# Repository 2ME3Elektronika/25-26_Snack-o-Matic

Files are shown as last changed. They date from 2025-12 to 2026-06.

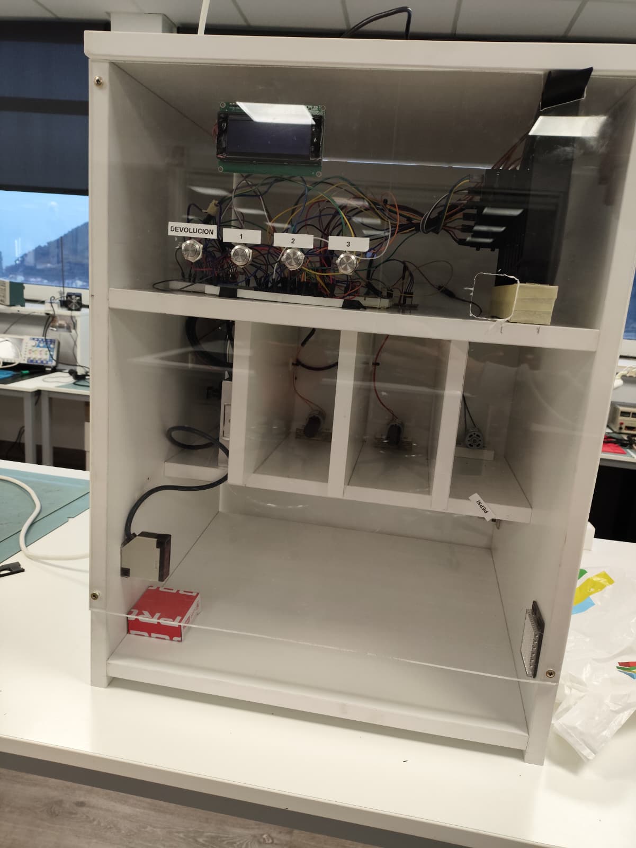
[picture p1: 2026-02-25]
Prototipos/Prototipo foto 2.jpeg

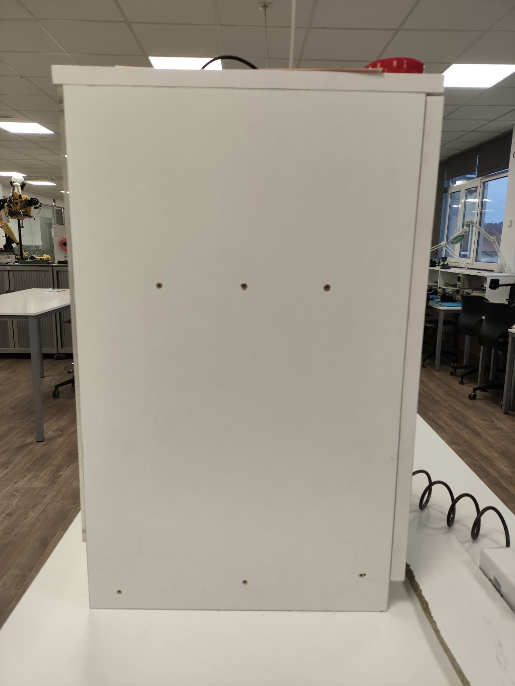
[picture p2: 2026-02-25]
Prototipos/Prototipo foto 3.jpeg

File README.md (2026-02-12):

# 25-26_Snack-o-Matic
# 🥤 Máquina Expendedora Inteligente

Proyecto de desarrollo de una máquina expendedora basada en Arduino, que integra sistemas mecánicos, electrónicos y de control para la validación de monedas y dispensado automático de productos.

---

## 📖 Descripción

Este proyecto tiene como objetivo el diseño y construcción de una máquina expendedora funcional, combinando electrónica, mecánica e impresión 3D.

Incluye el desarrollo del sistema de validación de monedas, el control de actuadores, la visualización de información al usuario y la gestión organizada de toda la documentación del proyecto.

---

## 🚀 Características principales

- Validación de monedas por sensores  
- Dispensado automático mediante motores y sinfines  
- Interfaz con pantalla LCD  
- Almacenamiento de datos en memoria EEPROM  
- Componentes mecánicos impresos en 3D  

---

## 🧱 Tecnologías utilizadas

- Arduino Mega 2560  
- Lenguaje C/C++  
- Impresión 3D (FDM)  
- Electrónica digital  
- Proteus y diseño de PCB  

---

## 📂 Estructura del repositorio

```text
/
├── Impresiones_3D/
├── Planos/
├── Organizacion_del_Proyecto/
├── Programacion/
├── Prototipos/
└── README.md

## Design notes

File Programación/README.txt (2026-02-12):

# 💻 Programación

Este directorio contiene el código fuente que gobierna el funcionamiento de la máquina expendedora.

Incluye el programa principal para Arduino y sus variantes optimizadas, desarrolladas para mejorar el rendimiento, la legibilidad y la fiabilidad del sistema.

---

## 📂 Contenido

Dentro de esta carpeta se incluyen:

- **Programa principal**  
  Código encargado de la gestión de monedas, control de actuadores, visualización en pantalla y lógica general del sistema.

- **Variantes optimizadas**  
  Versiones alternativas del programa que incorporan mejoras en organización, eficiencia o estabilidad.

---

## ⚙️ Plataforma

- Placa: Arduino Mega 2560  
- Lenguaje: C / C++ (entorno Arduino IDE)

---

## 📚 Librerías utilizadas

- Servo.h  
- LiquidCrystal_I2C.h  
- EEPROM.h  

---

## ▶️ Carga del programa

1. Abrir el archivo `.ino` en Arduino IDE  
2. Seleccionar placa: *Arduino Mega 2560*  
3. Seleccionar puerto COM  
4. Subir el programa  

---

## 🧠 Funcionalidades principales

- Lectura de sensores de monedas  
- Cálculo de importe introducido  
- Control de servos y motores  
- Actualización de pantalla LCD  
- Almacenamiento de datos en EEPROM  

---

## 🧪 Pruebas

Cada variante debe probarse de forma independiente antes de su uso en el sistema final.

---

## 📜 Licencia

Este código se distribuye bajo la misma licencia que el proyecto principal.

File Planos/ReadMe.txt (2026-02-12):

# 📐 Planos

Este directorio contiene los planos necesarios para la construcción completa de la máquina expendedora, incluyendo documentación mecánica, eléctrica y electrónica.

Los archivos incluidos permiten comprender la arquitectura del sistema y facilitan su fabricación, montaje y mantenimiento.

---

## 📂 Contenido

Dentro de esta carpeta se incluyen los siguientes tipos de planos:

- **Planos mecánicos**  
  Dibujos técnicos de la estructura, soportes y elementos físicos de la máquina.

- **Planos eléctricos**  
  Esquemas de cableado y distribución de energía del sistema.

- **Plano de PCB de relés**  
  Diseño de una placa electrónica que permite conmutar señales y gestionar una línea de 24V a partir de una fuente principal de 5V.

---

## ⚡ PCB de relés – Descripción

La PCB está diseñada para:

- Recibir alimentación a 5V  
- Activar relés mediante señales de control  
- Permitir la conmutación de cargas a 24V  

Su función principal es actuar como interfaz entre la electrónica de control y los actuadores que trabajan a mayor tensión.

---

## 📁 Formato de archivos

Los planos pueden encontrarse en formatos como:

- `.PDF` → Visualización  
- `.DWG` / `.DXF` → CAD  
- `.SCH` / `.PCB` → Diseño electrónico  
- `.PNG` / `.JPG` → Vista rápida  

---

## 🛠️ Software recomendado

- AutoCAD / DraftSight  
- KiCad / EasyEDA  
- Fusion 360  

---

## ⚠️ Notas

- Verificar siempre versiones actualizadas antes de fabricar.  
- Revisar escalas y cotas en planos mecánicos.  
- Comprobar polaridades y tensiones en esquemas eléctricos.

---

## 📜 Licencia

Esta documentación se distribuye bajo la misma licencia que el proyecto principal.

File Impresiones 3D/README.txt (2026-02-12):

# 🖨️ Impresiones 3D

Este directorio contiene los modelos 3D utilizados en el proyecto.  
Los archivos aquí incluidos permiten fabricar las piezas mecánicas necesarias para el correcto funcionamiento del sistema de dispensado y validación de monedas.

Todos los modelos están optimizados para impresión FDM y pueden ser modificados según las necesidades del proyecto.

---

## 📦 Contenido

Dentro de esta carpeta se incluyen los siguientes modelos:

- **Divisor de monedas**  
  Permite separar y dirigir las monedas según su valor hacia los sensores correspondientes.

- **Entrada de monedas**  
  Canal guía por el que el usuario introduce la moneda al sistema.

- **Eje para servos**  
  Eje especial diseñado para acoplarse al servo y desplazar las monedas dentro del divisor.

- **Soporte para motores de sinfín**  
  Estructura que fija los motores encargados de empujar los sinfines.

- **Acoplador motor–sinfín**  
  Pieza que une el eje del motor con el sinfín para transmitir el movimiento.

---

## 🧱 Formato de archivos

Los modelos se proporcionan principalmente en:

- `.STL` → Listos para imprimir  
- `.STEP` / `.IGES` → Editables (si aplica)

---

## 🖨️ Parámetros de impresión recomendados

- Altura de capa: `0.2 mm`  
- Relleno (infill): `20–30%`  
- Material: `PLA` o `PETG`  
- Soportes: Solo cuando sea necesario  

> Nota: Ajustar orientación y soportes según cada pieza.

---

## ⚙️ Compatibilidad

Las piezas están diseñadas para integrarse con:

- Servos estándar (SG90 / MG90 o similares)  
- Motores DC con eje cilíndrico  
- Sistemas de sinfín para dispensado

---

## ✏️ Personalización

Los archivos editables permiten:

- Modificar diámetros de eje  
- Ajustar tolerancias  
- Escalar piezas

Se recomienda usar software CAD como Fusion 360, FreeCAD o SolidWorks.

---

## 📜 Licencia

Los modelos 3D se distribuyen bajo la misma licencia que el proyecto principal.

---

## 📌 Notas

Antes de imprimir en lote, se recomienda realizar una impresión de prueba para verificar tolerancias y ajustes.

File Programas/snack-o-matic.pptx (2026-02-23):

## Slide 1

PROYECTO 25–26 // WALLY SL

Snack-o-Matic

Tu Marca, Tu Máquina

Máquina expendedora funcional basada en Arduino Mega 2560.
Electrónica custom, mecánica 3D y software embebido.

Arduino Mega 2560

Servos SG90

Motores DC

C / C++

Impresión 3D FDM

Proteus / PCB

LCD I²C

EEPROM

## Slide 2

01 // Introducción

Objetivo & Contexto

OBJETIVO DEL PROYECTO

Diseñar y construir una máquina expendedora inteligente y personalizable que gestiona inserción de monedas, dispensa productos y devuelve cambio exacto de forma autónoma.

CONTEXTO — WALLY SL

Las máquinas genéricas no permiten personalización de marca. Wally SL (David, Ibon e Iker) ofrece un servicio integral: diseño, fabricación, ubicación y mantenimiento con identidad propia.

EMPRESA

ESTADO

Prototipo funcional

AÑO

2025–2026

Wally SL — David, Ibon & Iker

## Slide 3

01 // Especificaciones

Especificaciones Técnicas

Arduino Mega 2560

MICROCONTROLADOR

C / C++ (Arduino IDE)

Impresión 3D FDM — PLA/PETG, 0.2 mm, 20-30% infill

LENGUAJE

FABRICACIÓN MECÁNICA

Proteus (simulación) + PCB relés custom (5V → 24V)

DISEÑO ELECTRÓNICO

LCD I²C 20×4 — pines SDA/SCL 20–21

INTERFAZ USUARIO

EEPROM interna Arduino — stock persistente

ALMACENAMIENTO

6 sensores INPUT_PULLUP — 5¢·10¢·20¢·50¢·1€·2€ (pines 14–19)

4 motores DC sinfín (pines 7–10) + fotocélula (pin 6)

SENSORES DE MONEDAS

6 servos SG90/MG90 (pines 27–32) — algoritmo greedy

DISPENSADO

DEVOLUCIÓN DE CAMBIO

4 producto + 1 devolución (pines 22–25, 33)

BOTONES

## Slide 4

02 // Arquitectura

Diagrama de Bloques

ENTRADAS

Sensores
Monedas

x6 · pines 14-19

Botones
Producto

x4 · pines 22-25

Botón
Devolución

pin 33

Fotocélula

pin 6

ARDUINO MEGA 2560

Unidad de control central

↓

↓

SALIDAS

Motores
Sinfín

x4 · pines 7-10

Servos
Cambio

x6 · pines 27-32

Pantalla
LCD

I²C pines 20-21

EEPROM

interna Arduino

PCB Relés

5V → 24V

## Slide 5

02 // Bloques Internos

Descripción de los Bloques

UNIDAD DE CONTROL

Máquina de dos estados: Estado 0 (lectura monedas) y Estado 1 (selección y dispensado).

VALIDACIÓN MONEDAS

6 sensores INPUT_PULLUP. Anti-rebote 100ms. Suma al saldo y guarda stock en EEPROM.

SISTEMA DISPENSADO

4 motores sinfín a 24V controlados por relés. Fotocélula confirma la salida del producto.

DEVOLUCIÓN CAMBIO

Algoritmo greedy: mayor denominación posible. Cada servo gira 0°→180°→0° por moneda.

LCD 20×4

Muestra saldo, precio seleccionado y estado del sistema. Avisa si no hay cambio disponible.

PCB RELÉS + EEPROM

PCB custom (5V→24V) diseñada en Proteus. EEPROM: stock persistente tras reinicio.

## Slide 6

03 // Descripción Detallada

Flujo de Operación

1. Validación
de Monedas

2. Selección y
Dispensado

3. Devolución
de Cambio

Moneda entra por el sensor

Usuario pulsa botón

Calcula cambio restante

Señal baja a LOW

1

Verifica saldo suficiente

1

Algoritmo greedy

1

Espera anti-rebote 100ms

2

Activa motor vía PCB relés

2

Servo 2€, 1€, 50¢...

2

3

3

3

Suma valor al saldo

4

Sinfín empuja producto

4

Cada servo: 0°→180°→0°

4

Guarda en EEPROM

5

Fotocélula detecta salida

5

Repite hasta saldo=0

5

Actualiza LCD

6

Motor se apaga

6

Pantalla: "Cambio devuelto"

6

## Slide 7

04 // Desarrollo del Proyecto

Problemas & Soluciones

⚠ PROBLEMA 01

Las RPM de los motores no están reguladas

✓ SOLUCIÓN PROPUESTA

Implementar puentes H (controladores PWM)

→

⚠ PROBLEMA 02

Los ejes de los servos no tienen margen suficiente para dispensar monedas

→

✓ SOLUCIÓN PROPUESTA

Rediseñar el mecanismo: expulsar la 2ª o 3ª moneda de la columna, dejando margen de movimiento

⚠ PROBLEMA 03

Escasez de material durante el proyecto

✓ SOLUCIÓN PROPUESTA

Adquirir todo el material al inicio y definir limitaciones desde el principio

→

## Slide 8

05 // Resolución de Incidencias

Arreglos & Estado

//01

PROBLEMA

Falta de sinfines

SOLUCIÓN / ESTADO

Fabricación propia de sinfines — inviable por peso y material. Limitación: solo 3 motores operativos.

✗

//02

PROBLEMA

Modelos 3D poco efectivos en la realidad

SOLUCIÓN / ESTADO

Rediseño y reimpresión de piezas modificando los modelos anteriores. Funcionamiento correcto.

✓

//03

PROBLEMA

Fallo técnico de último momento en un motor

SOLUCIÓN / ESTADO

Retirada del motor averiado. Imposible reparar a tiempo.

✗

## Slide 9

06 // Cierre

Conclusiones & Mejoras

REQUISITOS CUMPLIDOS

Máquina expendedora completamente funcional: validación de 6 denominaciones, dispensado de 4 productos, cambio exacto, LCD y EEPROM persistente.

VALORACIÓN GENERAL

Integración real de electrónica, programación, CAD e impresión 3D. Destaca la PCB de relés y la robustez del algoritmo greedy de cambio.

MEJORAS FUTURAS

Controladores PWM (puentes H) para regular motores

01

Canaletas para orden del cableado

05

Fuentes de alimentación 12V y 5V dedicadas

02

Componentes de seguridad adicionales

06

Sinfines comerciales adecuados para los motores

03

Compuertas mecánicas + LCD integrada en metacrilato

07

Rediseño del mecanismo de dispensado de servos

04

Cintas transportadoras como alternativa a los sinfines

08

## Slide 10

FIN DE LA PRESENTACIÓN

Snack-o-Matic

Wally SL · David, Ibon & Iker

Arduino Mega 2560 // C / C++ // 2025–2026

Arduino Mega 2560

Servos SG90

Motores DC 24V

C / C++

Impresión 3D FDM

Proteus / PCB

LCD I²C 20×4

EEPROM

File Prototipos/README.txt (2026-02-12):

# 🧪 Prototipos

Este directorio contiene imágenes del prototipo desarrollado durante las diferentes fases del proyecto.

Las fotografías permiten visualizar la evolución del sistema, la integración de componentes y la validación práctica de los distintos subsistemas.

---

## 📂 Contenido

Dentro de esta carpeta se incluyen:

- Imágenes del montaje mecánico  
- Imágenes del cableado y electrónica  
- Imágenes de pruebas de funcionamiento  

Cada imagen puede ir acompañada de una breve descripción indicando qué se muestra y en qué fase del proyecto se tomó.

---

## 🖼️ Recomendaciones

- Usar imágenes nítidas y bien iluminadas  
- Nombrar los archivos de forma descriptiva  
  - Ejemplo: `prototipo_fase1.jpg`  
  - Ejemplo: `montaje_electronica_v2.png`  
- Añadir comentarios breves si es necesario

---

## 📌 Objetivo

Mostrar de forma visual el proceso de desarrollo y validación del prototipo de la máquina expendedora.

---

## 📜 Licencia

Las imágenes se distribuyen bajo la misma licencia que el proyecto principal.

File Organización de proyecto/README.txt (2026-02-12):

# 📁 Organización del Proyecto

Este directorio contiene la documentación relacionada con la gestión, planificación y organización general del proyecto.

Aquí se agrupan los documentos necesarios para comprender cómo se ha estructurado el desarrollo, qué recursos se utilizan y bajo qué condiciones se lleva a cabo el proyecto.

---

## 📂 Contenido

Dentro de esta carpeta se incluyen los siguientes documentos:

- **Listados de material (BOM – Bill of Materials)**  
  Relación completa de componentes utilizados en el proyecto, incluyendo versiones, cantidades y observaciones.

- **Contrato de trabajo**  
  Documento que define las condiciones de colaboración entre las partes implicadas.

- **Planificación del proyecto**  
  Cronogramas, fases de desarrollo y distribución de tareas.

- **Presentación comercial**  
  Documentación relacionada con la presentación para atraer a los clientes potenciales.

---

## 📑 Formato de archivos

Los documentos pueden encontrarse en formatos como:

- `.PDF`  
- `.DOCX`  
- `.XLSX`  
- `.PNG` / `.JPG`  

---

## 🧠 Buenas prácticas

- Mantener los documentos actualizados.  
- Indicar fecha y versión en cada archivo.  
- Utilizar nomenclatura clara y coherente.

---

## ⚠️ Notas

Esta documentación es de carácter organizativo y no afecta directamente al funcionamiento del código, pero es esencial para la correcta ejecución del proyecto.

---

## 📜 Licencia

Esta documentación se distribuye bajo la misma licencia que el proyecto principal.

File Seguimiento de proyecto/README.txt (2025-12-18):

Procedimiento de las actas:

  - Cada miércoles cada miembro del grupo tendrá un acta hecho de lo que ha hecho la anterior semana, esto es, si la semana anterior uno de los miembros ha hecho el
    plano eléctrico en el acta de la semana actual especificará que lo ha hecho. También se podrán especificar en los actas cualquier tipo de queja que se pueda tener
    desde el proceso de creación hasta de las circunstancias (ya sea falta de tiempo por X o Y razón, ya sea por problemas entre miembros del equipo...). Por último,
    se dirá qué planea hacer esa semana.

  - Los jueves el coordinador se reunirá con la profesora responsable para hacer un seguimiento del proyecto y hablar sobre los problemas que han podido surgir y
    cosas que se pueden hacer para lidiar con ello.

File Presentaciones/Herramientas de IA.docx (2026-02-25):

Herramientas de IA utilizadas para la creación del video de presentación:

- Sora2.
- Adobe Firefly.
- Copilot.

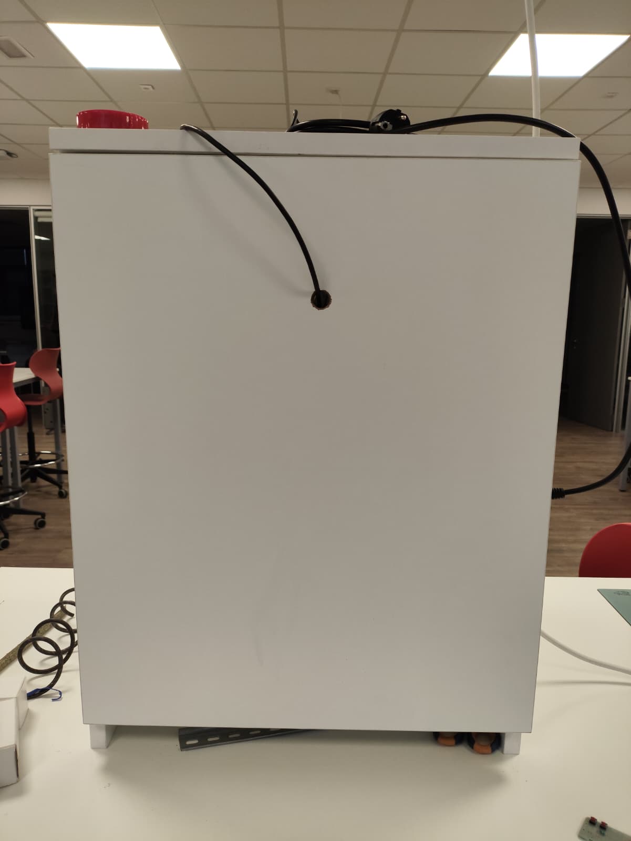
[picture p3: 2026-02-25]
Prototipos/Prototipo foto 4.jpeg

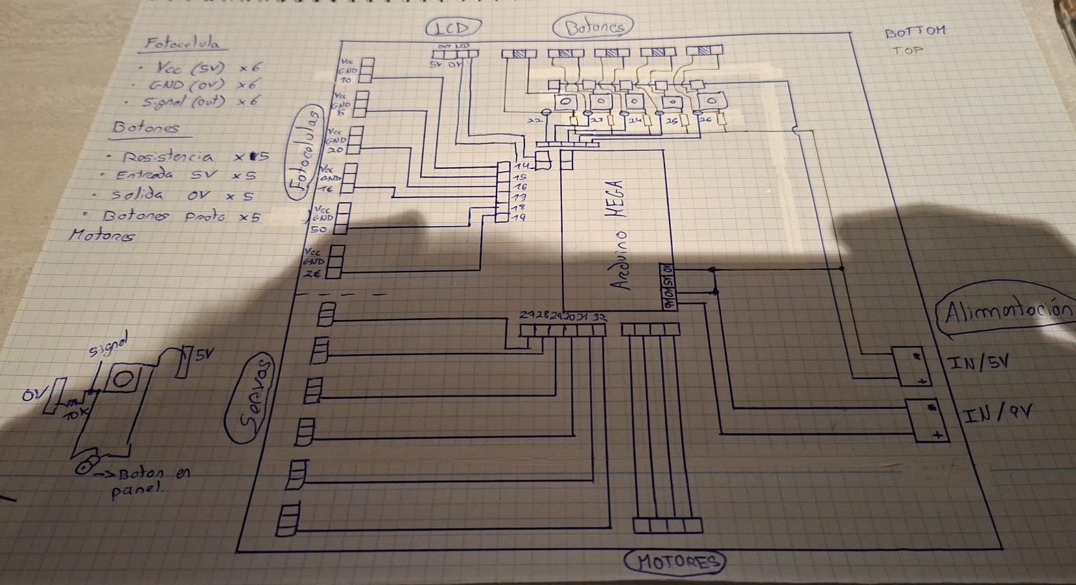
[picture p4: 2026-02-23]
Planos/Planos Eléctricos/Plano PCB - Cableado.jpeg

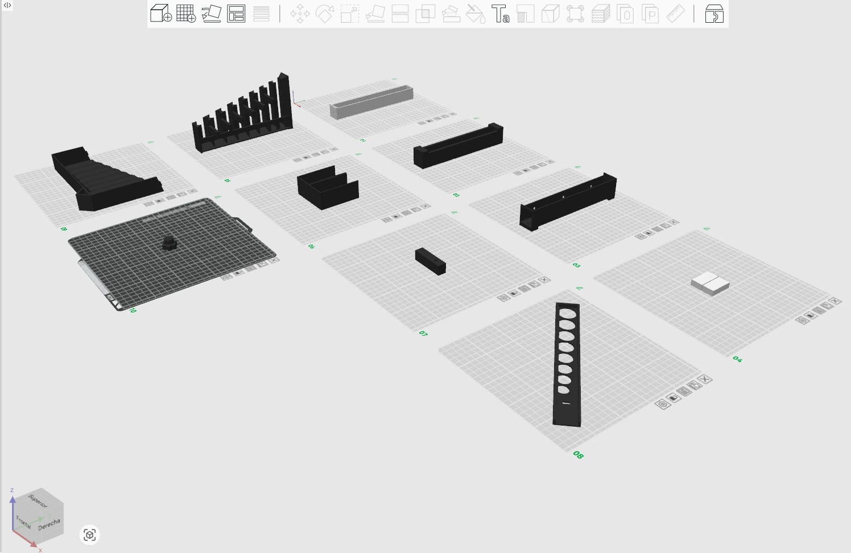
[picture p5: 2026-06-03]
Impresiones 3D/Monedero/Monedero Completo.jpg

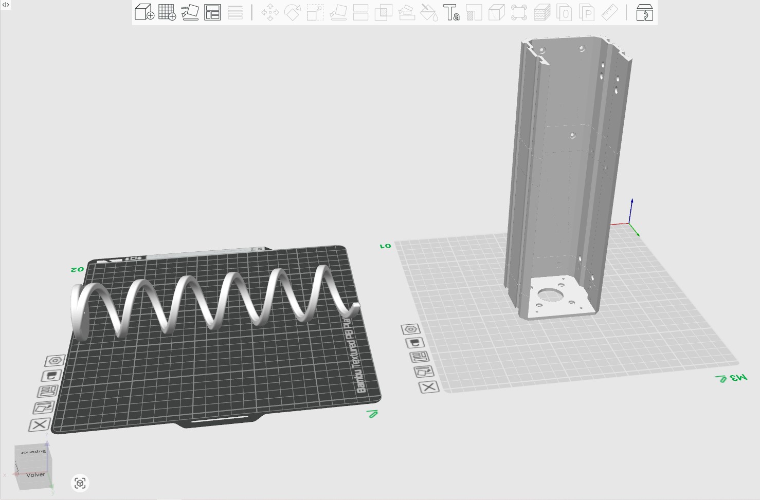
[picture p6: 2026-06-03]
Impresiones 3D/Modulos/Modulos.jpg

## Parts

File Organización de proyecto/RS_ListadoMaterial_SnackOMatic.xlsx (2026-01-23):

Material | Precio (Iva incluido) | Cantidad |  | Link
Fuente de alimentación 24V | 52.39€ | 1 |  | https://es.farnell.com/tdk-lambda/drb-50-24-1/power-supply-50w-24v-2-1a/dp/2366213
Fuente de alimentación 12V | 28.39€ | 1 |  | https://es.farnell.com/vigortronix/vtx-211-060-212/power-supply-ac-dc-1-output-54w/dp/3870204
Fuente de alimentación 5V | 26.23€ | 1 |  | https://es.farnell.com/ideal-power/56ysd30s-0503000/fuente-de-alimentaci-n-ac-dc-5v/dp/3798147
Motor DC | 19.94€ | 4 | Pedido y pendiente de recibir | https://es.rs-online.com/web/p/motores-dc/2483687
Arduino UNO R3 | 24.54€ | 1 | Entregado | https://es.farnell.com/arduino/a000066/arduino-uno-placa-de-evaluaci/dp/2075382?gross_price=true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
Arduino MEGA | 44.08€ | 1 | Entregado | https://es.farnell.com/arduino/a000067/arduino-mega2560-rev3-placa/dp/2212779?gross_price=true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
Relés SMD | 24.20€ | 10 | En pedido | https://es.farnell.com/hongfa/hfd4-5-s1r/rel-se-al-corto-plazo-5v-2a-smt/dp/4733579?gross_price=true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
Rollos de cable | 21.85€ | 3 |  | https://www.leroymerlin.es/productos/cable-lexman-h07v-k-100-metros-1-5-mm2-color-marron-19303333.html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 | 1 Unidad de cable azul, una de marrón y tierra
Pulsador | 52.15€ | 5 | Pedido y pendiente de recibir | https://es.rs-online.com/web/p/botones-pulsadores/2489135
Carril DIN | 13.90€ | 2 | Pedido y pendiente de recibir | https://es.rs-online.com/web/p/carriles-din/6485722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
Bornes | 13.06€ | 20 | Pedido y pendiente de recibir | https://es.rs-online.com/web/p/bornes-de-carril-din/0802783
Bornes de tierra | 28.95€ | 6 | Pedido y pendiente de recibir | https://es.rs-online.com/web/p/bornes-de-carril-din/0193130
Bridas | 5.33€ | 1 (Pack) |  | https://es.rs-online.com/web/p/bridas/2012390?gb=a
Punteras de cable | 13.15€ | 1 (Pack) |  | https://es.rs-online.com/web/p/punteras-huecas/5132613?gb=a
Conector macho alimentación | 1.49€ | 1 | Pedido y pendiente de recibir | https://es.rs-online.com/web/p/conectores-iec/8117207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
Terminal Faston | 6.87€ | 1 |  | https://es.rs-online.com/web/p/terminales-de-lengueta/0304817
Fotocelula arduino (Pack de 5) | 8.99€ | 2 | Entregado | https://www.amazon.es/ANGEEK-Unidades-TCRT5000-Reflectante-Lichtschranke/dp/B07Q81NTBX?adgrpid=96746003440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
Fotocelula | 13.79€ | 1 | En pedido | https://www.amazon.es/Jadeshay-Interruptor-fotoel%C3%A9ctrico-retrorreflectante-proximidad/dp/B0D7HBPN14
Cable de alimentación | 31.08€ | 1 | Pedido y pendiente de recibir | https://es.rs-online.com/web/p/cables-de-alimentacion-para-equipos/6151154?gb=a
Servo motor | 4.11€ | 6 | Pedido y pendiente de recibir | https://es.rs-online.com/web/p/kits-de-robots-educativos/2049891?gb=a
PRECIO TOTAL (IVA INCLUIDO) | 427.17€

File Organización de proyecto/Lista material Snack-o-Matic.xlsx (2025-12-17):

Material | Precio (Iva incluido) | Cantidad | Link
Tablero OSB3 250 x 125 x 1,2 cm | 24.50 € | 2 | https://www.bricodepot.es/5063022548092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
Escuadra 3 partes con nervio 130 x 30 x 72 mm | 2€ | 15 | https://www.bricodepot.es/escuadra-3-partes-con-nervio-130-x-30-x-72-mm-4004338341398
Pack 2 bisagras cazoleta ø 35 mm super acodada | 1.78€ | 3 | https://www.bricodepot.es/pack-2-bisagras-cazoleta-35-mm-super-acodada-8421807130646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
Fuente de alimentación 24V | 25.98€ | 1 | https://www.amazon.es/Kingwen-Alimentacion-Transformador-Interruptor-Potencia/dp/B09JKJGT4M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
Fuente de alimentación 12V | 17.99€ | 1 | https://www.amazon.es/Kingwen-Alimentacion-Transformador-Interruptor-Potencia/dp/B08QCNYLY8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
Fuente de alimentación 5V | 13.99€ | 1 | Fuente de alimentación conmutada 5V 10A 50W DC Adaptador de alimentación AC 100V/240V a DC-5V, transformador ANGEEK, adecuado para tiras LED, impresoras 3D, proyectos de iluminación, etc. : Amazon.es (https://www.amazon.es/alimentaci%C3%B3n-transformador-ANGEEK-impresoras-iluminaci%C3%B3n/dp/B0BX2KZ3D9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)
Cerrojo doble cilindro 25x40 mm | 12.95€ | 1 | https://www.bricodepot.es/cerrojo-doble-cilindro-25x40-mm-3150269002202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
Caja 100 unid. Tornillo madera spax cabeza plana yellox 3,0x12mm | 7.64€ | 1 | https://www.bricodepot.es/tirafondo-cabeza-plana-yellox-m-3x12-mm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
Vidrio plástico transparente liso de 2 mm de grosor y 125x50cm | 15.05€ | 1 | https://www.leroymerlin.es/productos/vidrio-plastico-transparente-liso-de-2-mm-de-grosor-y-125x50cm-81902610.html
Motor DC | 19.94€ | 4 | https://es.rs-online.com/web/p/motores-dc/2483687
Arduino UNO R3 | 24.54€ | 1 | https://es.farnell.com/arduino/a000066/arduino-uno-placa-de-evaluaci/dp/2075382?gross_price=true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
Arduino MEGA | 44.08€ | 1 | https://es.farnell.com/arduino/a000067/arduino-mega2560-rev3-placa/dp/2212779?gross_price=true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
Relés SMD | 24.20€ | 10 | https://es.farnell.com/hongfa/hfd4-5-s1r/rel-se-al-corto-plazo-5v-2a-smt/dp/4733579?gross_price=true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
Rollos de cable | 21.85€ | 3 | https://www.leroymerlin.es/productos/cable-lexman-h07v-k-100-metros-1-5-mm2-color-marron-19303333.html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 | 1 Unidad de cable azul, una de marrón y tierra
Display LCD | 21.02€ | 1 | https://es.rs-online.com/web/p/displays-monocromos-lcd/2109029?matchtype=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
Pulsador | 52.15€ | 5 | https://es.rs-online.com/web/p/botones-pulsadores/2489135
Ladrón | 2.45€ | 1 | https://www.leroymerlin.es/productos/base-multiple-3-tomas-con-1-metro-94994132.html
Carril DIN | 13.90€ | 2 | https://es.rs-online.com/web/p/carriles-din/6485722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
Interruptor automático General | 70.91€ | 1 | https://es.rs-online.com/web/p/interruptores-automaticos-magnetotermicos/7467731?gb=a
Interruptor diferencial | 69.76€ | 1 | https://es.rs-online.com/web/p/interruptores-diferenciales/2387390
Pequeño magnetotermico | 53.49€ | 3 | https://es.rs-online.com/web/p/interruptores-automaticos-magnetotermicos/2768734
Bornes | 13.06€ | 10 | https://es.rs-online.com/web/p/bornes-de-carril-din/0802783
Bornes de tierra | 28.95€ | 5 | https://es.rs-online.com/web/p/bornes-de-carril-din/0193130
Toma de corriente de carril din | 75.60€ | 1 | https://es.rs-online.com/web/p/clavijas-electricas/2013752?gb=a
Pegatinas | 11.95€ | 1 | https://www.amazon.es/MDlabels-Etiquetas-t%C3%A9rmicas-unidades-permanente/dp/B09FSZQCRF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
Conector macho alimentación | 1.49€ | 1 | https://es.rs-online.com/web/p/conectores-iec/8117207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
Terminal Faston | 6.87€ | 1 | https://es.rs-online.com/web/p/terminales-de-lengueta/0304817
Interruptor balancin rojo | 4.54€ | 1 | https://es.rs-online.com/web/p/interruptores-de-balancin/1858229?gb=a
Fotocelula arduino (Pack de 5) | 8.99€ | 2 | https://www.amazon.es/ANGEEK-Unidades-TCRT5000-Reflectante-Lichtschranke/dp/B07Q81NTBX?adgrpid=96746003440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
Tira LED 2m 5V | 10.99€ | 1 | https://www.amazon.es/MUSUNIA-retroiluminaci%C3%B3n-autoadhesivo-dormitorio-iluminaci%C3%B3n/dp/B0FFH32R9Z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
Fotocelula | 13.79€ | 1 | https://www.amazon.es/Jadeshay-Interruptor-fotoel%C3%A9ctrico-retrorreflectante-proximidad/dp/B0D7HBPN14
Cable de alimentación | 31.08€ | 1 | https://es.rs-online.com/web/p/cables-de-alimentacion-para-equipos/6151154?gb=a
Servo motor | 4.11€ | 6 | https://es.rs-online.com/web/p/kits-de-robots-educativos/2049891?gb=a
Ventilador | 13.10 € | 4 | https://es.rs-online.com/web/p/ventiladores-axiales/6688801
20 escuadras ángulo de 30x30x30 mm | 3.40 € | 1 | https://www.leroymerlin.es/productos/20-escuadras-angulo-de-30x30x30-mm-15904686.html?aw_affid=376257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

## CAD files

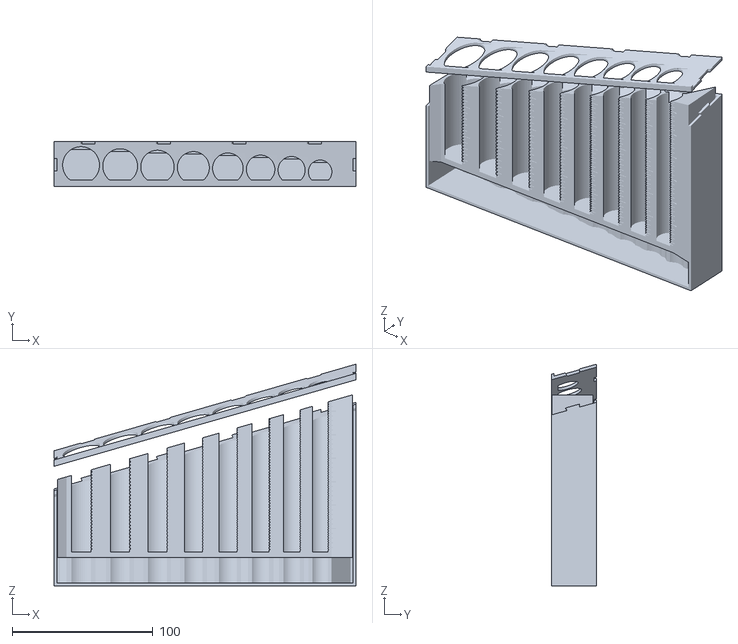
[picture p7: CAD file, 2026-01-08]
Impresiones 3D/Divisor de monedas/Modelos sin modificar/sorter-customizer_all_unassembled20150919-17856-tkl14k-0.stl
214.9 x 32.1 x 157.7

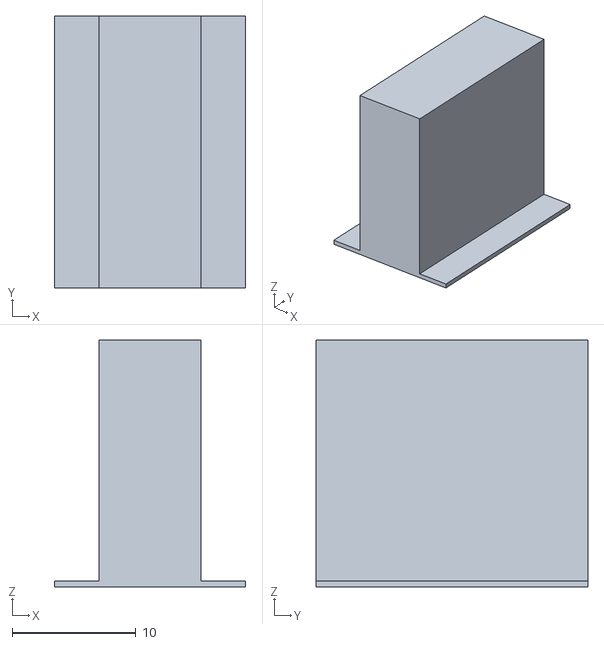
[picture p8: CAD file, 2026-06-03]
Impresiones 3D/cierre2.stl
15.5 x 22.0 x 20.0

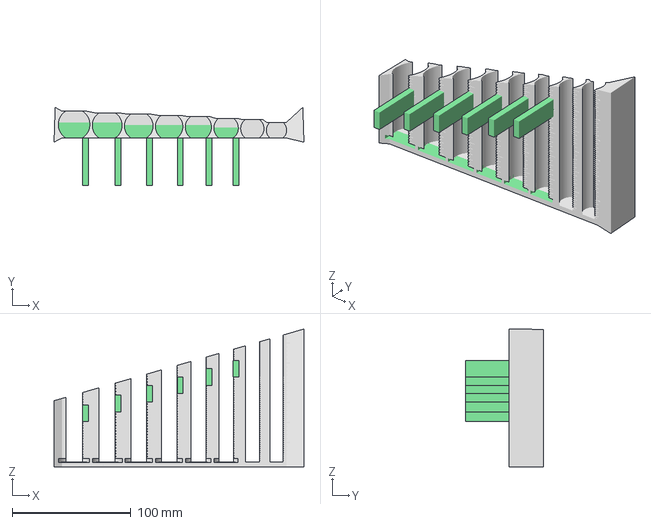
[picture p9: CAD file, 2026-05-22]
Impresiones 3D/Divisor de monedas/Modelos personalizados/Cilindros_Sorter_V2.3mf
210.1 x 65.9 x 115.9 mm

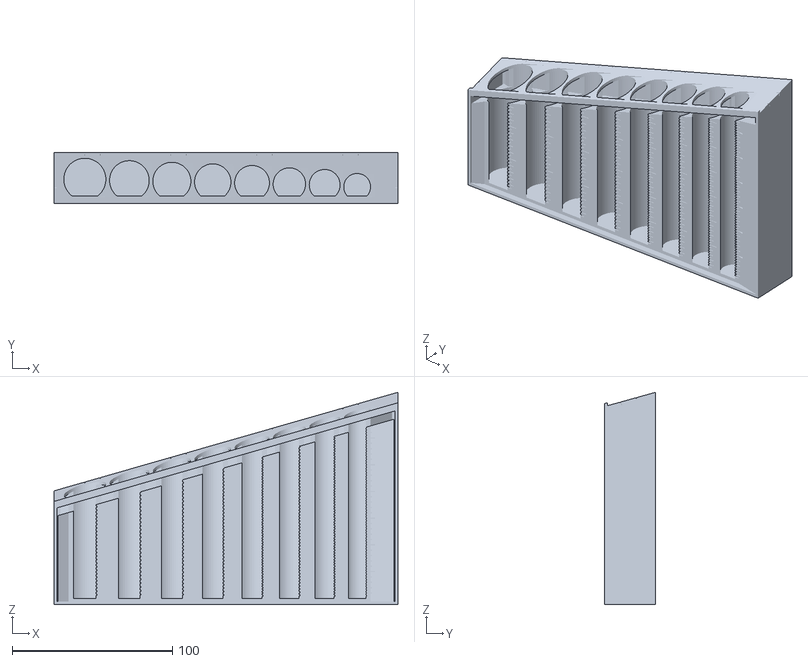
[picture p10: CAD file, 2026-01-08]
Impresiones 3D/Divisor de monedas/Modelos sin modificar/sorter-customizer_all20150919-17856-eytmq2-0.stl
214.9 x 32.1 x 132.7

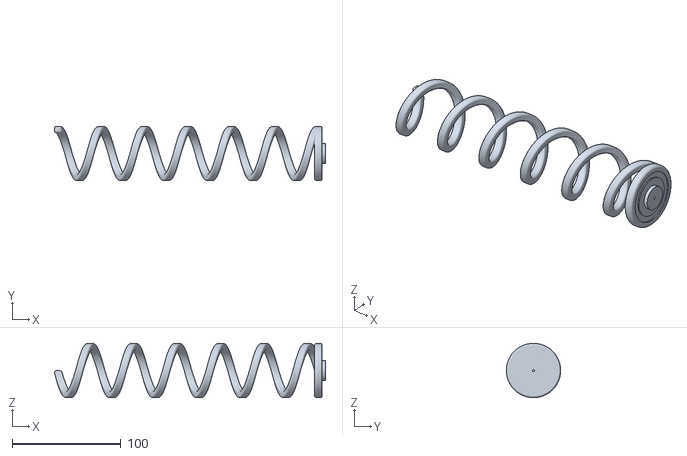
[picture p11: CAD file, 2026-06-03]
Impresiones 3D/Modulos/Espiral 005.stl
249.4 x 50.0 x 50.0

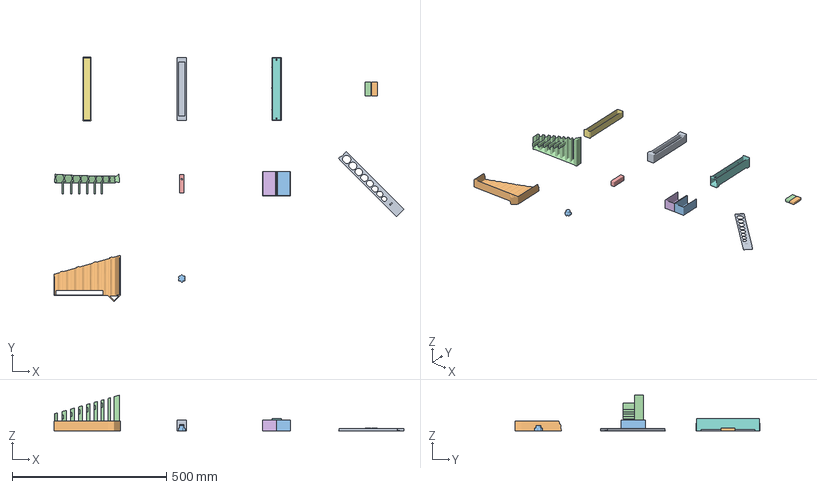
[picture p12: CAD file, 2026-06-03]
Impresiones 3D/Monedero/Monedero completo.3mf
1134.7 x 792.7 x 115.9 mm
Guia v2.stl x 2
Separador lateral v2.stl x 2
Separador altura 20mm.stl
Recoge monedas central.stl
traga monedas v6.stl
M3.stl
Cilindros_Sorter_V4

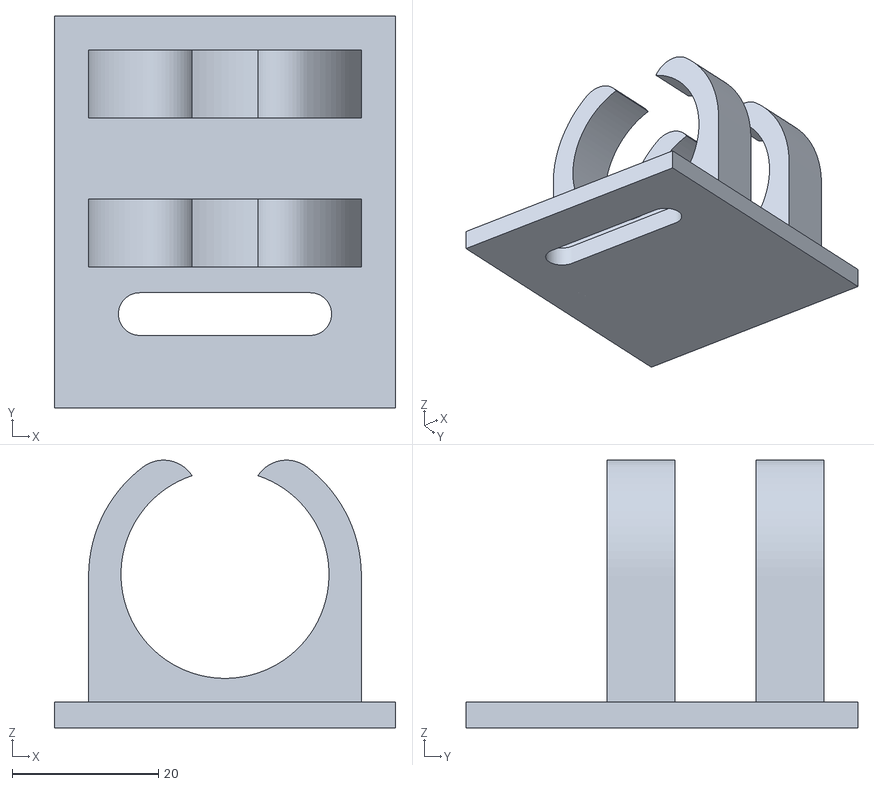
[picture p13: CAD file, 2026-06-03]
Impresiones 3D/Soporte motor/Soprte part 2.stl
46.6 x 53.5 x 36.5

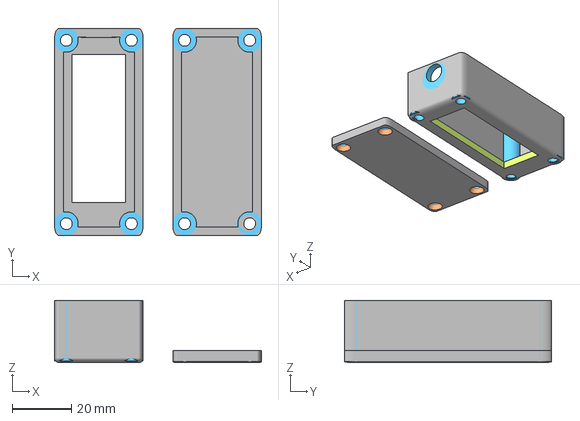
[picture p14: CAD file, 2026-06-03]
Impresiones 3D/Caja para circuito v4.3mf
70.0 x 70.0 x 21.0 mm

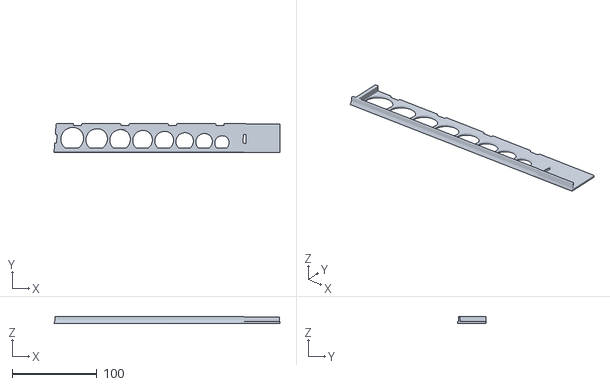
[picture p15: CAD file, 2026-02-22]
Impresiones 3D/Divisor de monedas/Modelos personalizados/Sorter_Topboard_Custom.stl
266.6 x 33.8 x 7.98

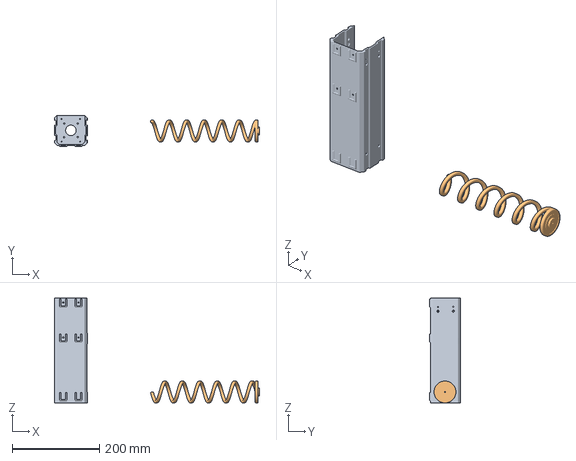
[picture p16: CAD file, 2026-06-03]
Impresiones 3D/Modulos/Modulos completo.3mf
469.4 x 72.0 x 240.0 mm
Modules003.stl
Coils005.stl

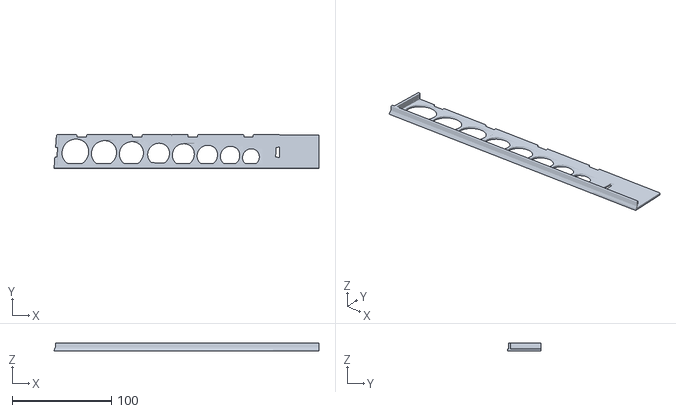
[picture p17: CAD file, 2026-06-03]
Impresiones 3D/Monedero/Coin Sorter v2.stl
266.9 x 33.8 x 7.98

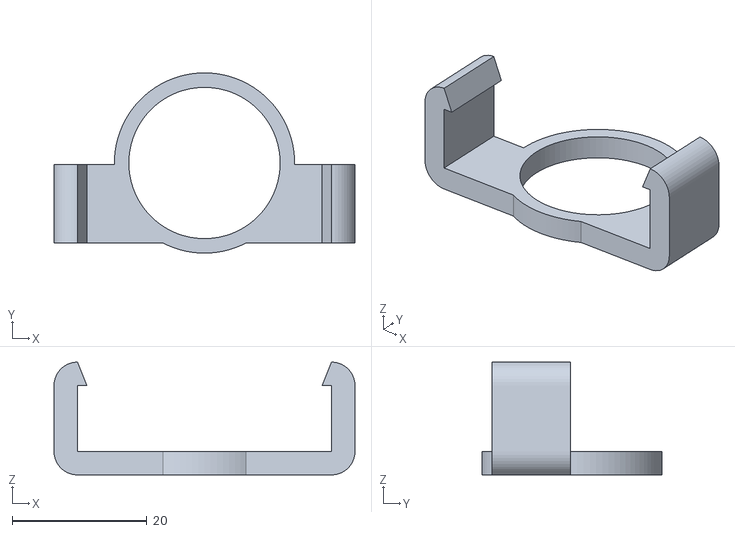
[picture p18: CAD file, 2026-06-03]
Impresiones 3D/Soporte motor/Soporte part 3.stl
44.7 x 26.8 x 16.8

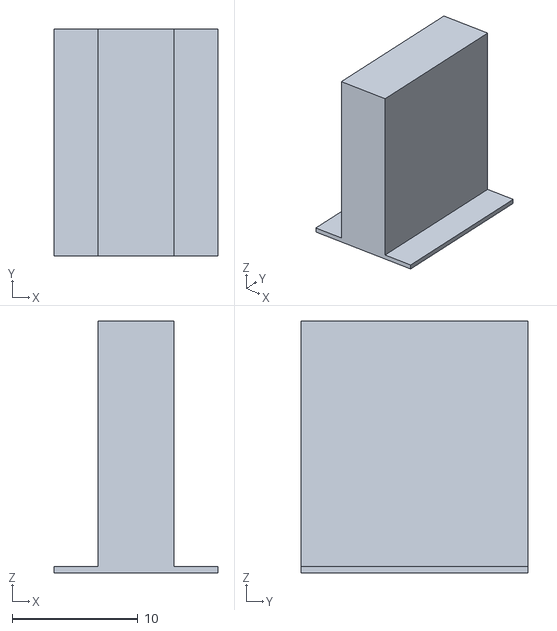
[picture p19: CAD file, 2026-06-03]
Impresiones 3D/cierre.stl
13.0 x 18.0 x 20.0

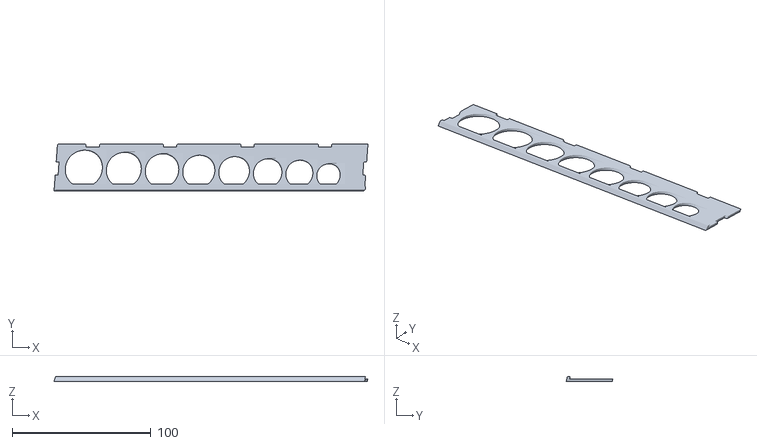
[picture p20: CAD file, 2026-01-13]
Impresiones 3D/Divisor de monedas/Modelos personalizados/sorter-customizer_topboard20150919-17856-n47bza-0_STL.stl
226.6 x 33.8 x 3.71

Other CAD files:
Impresiones 3D/Divisor de monedas/Modelos sin modificar/sorter-customizer_basebox20150919-17856-1al7uiw-0.stl
Impresiones 3D/Modulos/Modulos 003.stl
Impresiones 3D/Monedero/Recoge monedas 4.3mf
Impresiones 3D/Soporte motor/Soporte part 1.3mf
Impresiones 3D/Devolucion 03.3mf
Impresiones 3D/Divisor de monedas/Modelos personalizados/Sorter_Custom_David_V1_STL.stl
Impresiones 3D/Divisor de monedas/Modelos personalizados/sorter-customizer_basebox20150919-17856-1al7uiw-0_STL.stl
Impresiones 3D/Divisor de monedas/Modelos sin modificar/sorter-customizer_topboard20150919-17856-n47bza-0.stl
Impresiones 3D/Divisor de monedas/Modelos sin modificar/sorter-customizer_tubes20150919-17856-3ho4m5-0.stl
Impresiones 3D/Monedero/Chasis_Sorter_V2.3mf
Impresiones 3D/Monedero/Cilindros_Sorter_V4.3mf
Impresiones 3D/Monedero/Guia v2.stl
Impresiones 3D/Monedero/M3.stl
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

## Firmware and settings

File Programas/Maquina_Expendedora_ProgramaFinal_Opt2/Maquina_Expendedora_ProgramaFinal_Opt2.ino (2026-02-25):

//Librerías
  #include <EEPROM.h>
  #include <Servo.h>
  #include <Wire.h>
  #include <LiquidCrystal_I2C.h>

//Pinout entradas
  //Entradas sensores divisor de monedas
    #define diezc 14
    #define cincoc 15
    #define veintec 16
    #define cienc 17
    #define cincuentac 18
    #define doscientosc 19

  //Entradas botones de selección
    #define boton1 22
    #define boton2 23
    #define boton3 24
    #define boton4 25
    #define botondev 33

  //Entrada fotocélula productos
    #define detector 6

//Pinout salidas
  //Servos dispensador de monedas
    Servo servodiez;
    Servo servocinco;
    Servo servoveinte;
    Servo servocien;
    Servo servocincuenta;
    Servo servodoscientos;

  //LCD (en el montaje hay que conectarlo a los pines 20 y 21 del Arduino Mega)
    LiquidCrystal_I2C lcd(0x27, 20, 4);

  //Motores sinfines (dispensador de productos)
    #define motor1 7 
    #define motor2 8
    #define motor3 9 
    #define motor4 10 

//Variables
    uint8_t cantidad10 = 0; //Indica la cantidad de monedas de 10 céntimos que hay en la máquina
    uint8_t cantidad5 = 0; //Indica la cantidad de monedas de 5 céntimos que hay en la máquina
    uint8_t cantidad20 = 0; //Indica la cantidad de monedas de 20 céntimos que hay en la máquina
    uint8_t cantidad100 = 0; //Indica la cantidad de monedas de 1 euro que hay en la máquina
    uint8_t cantidad50 = 0; //Indica la cantidad de monedas de 50 céntimos que hay en la máquina
    uint8_t cantidad200 = 0; //Indica la cantidad de monedas de 2 euros que hay en la máquina

    int estadosensor10 = 0; //Indica si el sensor de 10 céntimos ha detectado una moneda
    int estadosensor5 = 0; //Indica si el sensor de 5 céntimos ha detectado una moneda
    int estadosensor20 = 0; //Indica si el sensor de 20 céntimos ha detectado una moneda
    int estadosensor100 = 0; //Indica si el sensor de 1 euro ha detectado una moneda
    int estadosensor50 = 0; //Indica si el sensor de 50 céntimos ha detectado una moneda
    int estadosensor200 = 0; //Indica si el sensor de 2 euros ha detectado una moneda

    int diez = 0; //Variable para la suma de monedas que tenemos
    int cinco = 0; //Variable para la suma de monedas que tenemos
    int veinte = 0; //Variable para la suma de monedas que tenemos
    int cien = 0; //Variable para la suma de monedas que tenemos
    int cincuenta = 0; //Variable para la suma de monedas que tenemos
    int doscientos = 0; //Variable para la suma de monedas que tenemos

    float suma = 0; //Ecuación para saber cuánto se ha metido (en cent)
    float sumaeuro = 0; //Ecuación para saber cuánto se ha metido (en euros)

    int estadoboton1 = 0; //Indica si el botón 1 se ha pulsado
    int estadoboton2 = 0; //Indica si el botón 2 se ha pulsado
    int estadoboton3 = 0; //Indica si el botón 3 se ha pulsado
    int estadoboton4 = 0; //Indica si el botón 4 se ha pulsado
    int devolucion = 0; //Indica si el botón de devolución se ha pulsado

    int estadodetector = 0; //Indica si el detector de productos se ha activado

    int Estado = 0; //Indica el estado de la máquina

void setup() 
  {
    Serial.begin (9600);
    //Inputs
      pinMode (diezc, INPUT_PULLUP);
      pinMode (cincoc, INPUT_PULLUP);
      pinMode (veintec, INPUT_PULLUP);
      pinMode (cienc, INPUT_PULLUP);
      pinMode (cincuentac, INPUT_PULLUP);
      pinMode (doscientosc, INPUT_PULLUP);
      pinMode (detector, INPUT);

      pinMode (boton1, INPUT);
      pinMode (boton2, INPUT);
      pinMode (boton3, INPUT);
      pinMode (boton4, INPUT);
      pinMode (botondev, INPUT);


    //Outputs
      pinMode (motor1, OUTPUT);
      pinMode (motor2, OUTPUT);
      pinMode (motor3, OUTPUT);
      pinMode (motor4, OUTPUT);

      servodiez.attach (27);
      servocinco.attach (28);
      servoveinte.attach (29);
      servocien.attach (30);
      servocincuenta.attach (31);
      servodoscientos.attach (32);

      digitalWrite (motor1, LOW);
      digitalWrite (motor2, LOW);
      digitalWrite (motor3, LOW);
      digitalWrite (motor4, LOW);

      servodiez.write (0);
      servocinco.write (0);
      servoveinte.write (0);
      servocien.write (0);
      servocincuenta.write (0);
      servodoscientos.write (0);

      cantidad10 = EEPROM.read (10);
      cantidad5 = EEPROM.read (5);
      cantidad20 = EEPROM.read (20);
      cantidad100 = EEPROM.read (100);
      cantidad50 = EEPROM.read (50);
      cantidad200 = EEPROM.read (200);
    
    //LCD
      lcd.init();
      lcd.backlight();
      Mensaje ();
  }

void Mensaje() 
  {
    lcd.clear();

    if (cantidad10 == 0 || cantidad5 == 0 || cantidad20 == 0 || cantidad100 == 0 || cantidad50 == 0 || cantidad200 == 0)
      {
        sumaeuro = suma / 100.00;
        lcd.print ("      Sin cambios    ");
        lcd.setCursor(0, 1);
        lcd.print ("       Saldo: ");
        lcd.print (sumaeuro);
        lcd.print ("$");
      }

    else
      {
        sumaeuro = suma / 100;
        lcd.print ("       Saldo: ");
        lcd.print (sumaeuro);
        lcd.print ("$");
      }

    if (estadoboton1 == HIGH)
      {
        while (estadoboton1 == HIGH)
          {
            estadoboton1 = digitalRead (boton1);
          }
        lcd.setCursor (0, 1);
        lcd.print ("  Precio: 1,20 euros");
      }

    if (estadoboton2 == HIGH)
      {
        while (estadoboton2 == HIGH)
          {
            estadoboton2 = digitalRead (boton2);
          }
        lcd.setCursor (0, 1);
        lcd.print ("  Precio: 1,50 euros");
      }

    if (estadoboton3 == HIGH)
      {
        while (estadoboton3 == HIGH)
          {
            estadoboton3 = digitalRead (boton3);
          }
        lcd.setCursor (0, 1);
        lcd.print ("  Precio: 1,70 euros");
      }

    if (estadoboton4 == HIGH)
      {
        while (estadoboton4 == HIGH)
          {
            estadoboton4 = digitalRead (boton4);
          }
        lcd.setCursor (0, 1);
        lcd.print ("     Precio: 2 euros");
      }
  }

void Lectura_de_5cent() //Lee si se ha introducido una moneda de 5 céntimos
  {
    estadosensor5 = digitalRead (cincoc);

    //Lectura sensor cinco cent.;
    if (estadosensor5 == LOW)
      {
        while (estadosensor5 == LOW)
          {
            estadosensor5 = digitalRead (cincoc);
            delay(100);
          }
        cinco = cinco + 5;
        cantidad5++;
        suma = diez + cinco + veinte + cien + cincuenta + doscientos;
        EEPROM.write (5, cantidad5);
        Mensaje ();
      }
  }

void Lectura_de_10cent() //Lee si se ha introducido una moneda de 10 céntimos
  {
    estadosensor10 = digitalRead (diezc);

    //Lectura sensor diez cent.
    if (estadosensor10 == LOW)
      {
        while (estadosensor10 == LOW)
          {
            estadosensor10 = digitalRead (diezc);
            delay (100);
          }
        diez = diez + 10;
        cantidad10++;
        suma = diez + cinco + veinte + cien + cincuenta + doscientos;
        EEPROM.write (10, cantidad10);
        Mensaje ();
      }
  }

void Lectura_de_20cent() //Lee si se ha introducido una moneda de 20 céntimos
  {
    estadosensor20 = digitalRead (veintec);

    //Lectura sensor veinte cent.
      if (estadosensor20 == LOW)
        {
          while (estadosensor20 == LOW)
            {
              estadosensor20 = digitalRead (veintec);
              delay(100);
            }
          veinte = veinte + 20;
          cantidad20++;
          suma = diez + cinco + veinte + cien + cincuenta + doscientos;
          EEPROM.write (20, cantidad20);
          Mensaje ();
        }
  }

void Lectura_de_50cent() //Lee si se ha introducido una moneda de 50 céntimos
  {
    estadosensor50 = digitalRead (cincuentac);

    //Lectura sensor cincuenta cent.
    if (estadosensor50 == LOW)
      {
        while (estadosensor50 == LOW)
          {
            estadosensor50 = digitalRead (cincuentac);
            delay (100);
          }
        cincuenta = cincuenta + 50;
        cantidad50++;
        suma = diez + cinco + veinte + cien + cincuenta + doscientos;
        EEPROM.write (50, cantidad50);
        Mensaje ();
      }
  }

void Lectura_de_1euro() //Lee si se ha introducido una moneda de 1 euro
  {
    estadosensor100 = digitalRead (cienc);

    //Lectura sensor cien cent.
    if (estadosensor100 == LOW)
      {
        while (estadosensor100 == LOW)
          {
            estadosensor100 = digitalRead (cienc);
            delay(100);
          }
        cien = cien + 100;
        cantidad100++;
        suma = diez + cinco + veinte + cien + cincuenta + doscientos;
        EEPROM.write (100, cantidad100);
        Mensaje ();
      }
  }

void Lectura_de_2euros() //Lee si se ha introducido una moneda de 2 euros
  {
    estadosensor200 = digitalRead (doscientosc);

    //Lectura sensor doscientos cent.
    if (estadosensor200 == LOW)
      {
        while (estadosensor200 == LOW)
          {
            estadosensor200 = digitalRead (doscientosc);
            delay (100);
          }
        doscientos = doscientos + 200;
        cantidad200++;
        suma = diez + cinco + veinte + cien + cincuenta + doscientos;
        EEPROM.write (200, cantidad200);
        Mensaje ();
      } 
  }
void Dispensa_Producto_1() //Reconoce y en caso de pedrise dispensa el producto denominado 1
  {
    estadoboton1 = digitalRead (boton1);

    if (estadoboton1 == HIGH && suma >= 120)
      {
        while (estadoboton1 == HIGH)
          {
            estadoboton1 = digitalRead (boton1);
          }
        
        suma = suma - 120;
        estadodetector = digitalRead (detector);
        lcd.clear();
        lcd.print ("      Dispensando...");

        while (estadodetector == LOW)
          {
            estadodetector = digitalRead (detector);
            digitalWrite (motor1, HIGH);
          }

        digitalWrite (motor1, LOW);

        while (suma > 0)
          {
            Devolver();
          }

        diez = 0;
        cinco = 0;
        veinte = 0;
        cien = 0;
        cincuenta = 0;
        doscientos = 0;
        suma = 0;
        lcd.clear();
        Mensaje();
      }

    if (estadoboton1 == HIGH) { Mensaje(); }
  }

void Dispensa_Producto_2() //Reconoce y en caso de pedrise dispensa el producto denominado 2
   {
    estadoboton2 = digitalRead (boton2);

    if (estadoboton1 == HIGH && suma >= 150)
      {
        while (estadoboton2 == HIGH)
          {
            estadoboton2 = digitalRead (boton2);
          }
        
        suma = suma - 150;
        estadodetector = digitalRead (detector);
        lcd.clear();
        lcd.print ("      Dispensando...");

        while (estadodetector == LOW)
          {
            estadodetector = digitalRead (detector);
            digitalWrite (motor2, HIGH);
          }

        digitalWrite (motor2, LOW);

        while (suma > 0)
          {
            Devolver();
          }

        diez = 0;
        cinco = 0;
        veinte = 0;
        cien = 0;
        cincuenta = 0;
        doscientos = 0;
        suma = 0;
        lcd.clear();
        Mensaje();
      }

    if (estadoboton2 == HIGH) { Mensaje(); }
   }

void Dispensa_Producto_3() //Reconoce y en caso de pedrise dispensa el producto denominado 3
  {
    if (estadoboton3 == HIGH && suma >= 170)
      {
        while (estadoboton3 == HIGH)
          {
            estadoboton3 = digitalRead (boton3);
          }
        
        suma = suma - 170;
        estadodetector = digitalRead (detector);
        lcd.clear();
        lcd.print ("      Dispensando...");

        while (estadodetector == LOW)
          {
            estadodetector = digitalRead (detector);
            digitalWrite (motor3, HIGH);
          }

        digitalWrite (motor3, LOW);

        while (suma > 0)
          {
            Devolver();
          }

        diez = 0;
        cinco = 0;
        veinte = 0;
        cien = 0;
        cincuenta = 0;
        doscientos = 0;
        suma = 0;
        lcd.clear();
        Mensaje();
      }

    if (estadoboton3 == HIGH) { Mensaje(); }
  }

void Dispensa_Producto_4 () //Reconoce y en caso de pedrise dispensa el producto denominado 4
  {
    if (estadoboton4 == HIGH && suma >= 200)
      {
        while (estadoboton4 == HIGH)
          {
            estadoboton4 = digitalRead (boton4);
          }

        suma = suma - 200;
        estadodetector = digitalRead (detector);
        lcd.clear();
        lcd.print ("      Dispensando...");

        while (estadodetector == LOW)
          {
            estadodetector = digitalRead (detector);
            digitalWrite (motor4, HIGH);
          }

        digitalWrite (motor4, LOW);

        while (suma > 0)
          {
            Devolver();
          }

        diez = 0;
        cinco = 0;
        veinte = 0;
        cien = 0;
        cincuenta = 0;
        doscientos = 0;
        suma = 0;
        lcd.clear();
        Mensaje();
      }

    if (estadoboton4 == HIGH) { Mensaje(); }
  }

void Boton_Devolucion() //Reconoce y en caso de pedrise devuelve el dinero introducido (no las mismas monedas, solo el mismo valor)
  {
    devolucion = digitalRead (botondev);

    if (devolucion == HIGH)
      {
        while (devolucion == HIGH)
          {
            devolucion = digitalRead (botondev);
          }

        lcd.clear();
        lcd.print ("      Devolviendo...");

        while (suma > 0)
          {
            Devolver();
          }
        lcd.clear();
        Mensaje();
      }
  }

void Devolver() //El sistema de cambios, se encarga de devolver el dinero correspondiente
  {
    if (suma >= 200 && cantidad200 > 0)
      {
        for (int angulo = 0; angulo <= 180; angulo++) 
          {
            servodoscientos.write(angulo);
            delay(15); 
          }

        for (int angulo = 180; angulo >= 0; angulo--) 
          {
            servodoscientos.write(angulo);
            delay(15);
          }

        suma = suma - 200;
        cantidad200 = cantidad200 - 1;
        EEPROM.write (200, cantidad200);
      }

    if (suma >= 100 && cantidad100 > 0)
      {
        for (int angulo = 0; angulo <= 180; angulo++) 
          {
            servocien.write(angulo);
            delay(15); 
          }

        for (int angulo = 180; angulo >= 0; angulo--) 
          {
            servocien.write(angulo);
            delay(15);
          }

        suma = suma - 100;
        cantidad100 = cantidad100 - 1;
        EEPROM.write (100, cantidad100);
      }

    if (suma >= 50 && cantidad50 > 0)
      {
        for (int angulo = 0; angulo <= 180; angulo++) 
          {
            servocincuenta.write(angulo);
            delay(15); 
          }

        for (int angulo = 180; angulo >= 0; angulo--) 
          {
            servocincuenta.write(angulo);
            delay(15);
          }

        suma = suma - 50;
        cantidad50 = cantidad50 - 1;
        EEPROM.write (50, cantidad50);
      }

    if (suma >= 20 && cantidad20 > 0)
      {
        for (int angulo = 0; angulo <= 180; angulo++) 
          {
            servoveinte.write(angulo);
            delay(15); 
          }

        for (int angulo = 180; angulo >= 0; angulo--) 
          {
            servoveinte.write(angulo);
            delay(15);
          }

        suma = suma - 20;
        cantidad20 = cantidad20 - 1;
        EEPROM.write (20, cantidad20);
      }

    if (suma >= 10 && cantidad10 > 0)
      {
        for (int angulo = 0; angulo <= 180; angulo++) 
          {
            servodiez.write(angulo);
            delay(15); 
          }

        for (int angulo = 180; angulo >= 0; angulo--) 
          {
            servodiez.write(angulo);
            delay(15);
          }

        suma = suma - 10;
        cantidad10 = cantidad10 - 1;
        EEPROM.write (10, cantidad10);
      }

    if (suma >= 5 && cantidad5 > 0)
      {
        for (int angulo = 0; angulo <= 180; angulo++) 
          {
            servocinco.write(angulo);
            delay(15); 
          }

        for (int angulo = 180; angulo >= 0; angulo--) 
          {
            servocinco.write(angulo);
            delay(15);
          }

        suma = suma - 5;
        cantidad5 = cantidad5 - 1;
        EEPROM.write (5, cantidad5);
      }
  }
void loop()
  { 
    switch (Estado)
      {
        case 0:

          Lectura_de_5cent(); //Lee si se ha introducido una moneda de 5 céntimos
          Lectura_de_10cent(); //Lee si se ha introducido una moneda de 10 céntimos
          Lectura_de_20cent(); //Lee si se ha introducido una moneda de 20 céntimos
          Lectura_de_50cent(); //Lee si se ha introducido una moneda de 50 céntimos
          Lectura_de_1euro(); //Lee si se ha introducido una moneda de 1 euro
          Lectura_de_2euros(); //Lee si se ha introducido una moneda de 2 euros

          if (suma > 0) { Estado = 1; }
        
        break;

        case 1:

          Dispensa_Producto_1(); //Reconoce y en caso de pedrise dispensa el producto denominado 1
          Dispensa_Producto_2(); //Reconoce y en caso de pedrise dispensa el producto denominado 2
          Dispensa_Producto_3(); //Reconoce y en caso de pedrise dispensa el producto denominado 3
          Dispensa_Producto_4(); //Reconoce y en caso de pedrise dispensa el producto denominado 4
          Boton_Devolucion(); //Reconoce y en caso de pedrise devuelve el dinero introducido (no las mismas monedas, solo el mismo valor)
          Estado = 0;

        break;
      }
  }

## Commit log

2026-01-21 Add 3D printing task to Acta_Ibon.txt
2026-01-21 Add task to assist with 3D printing
